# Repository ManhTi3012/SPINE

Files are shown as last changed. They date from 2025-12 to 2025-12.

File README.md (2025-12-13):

# S.P.I.N.E
**Stackable Power Integration & Network Electronics**

<p align="center" style="display: flex; gap: 10px;">
  
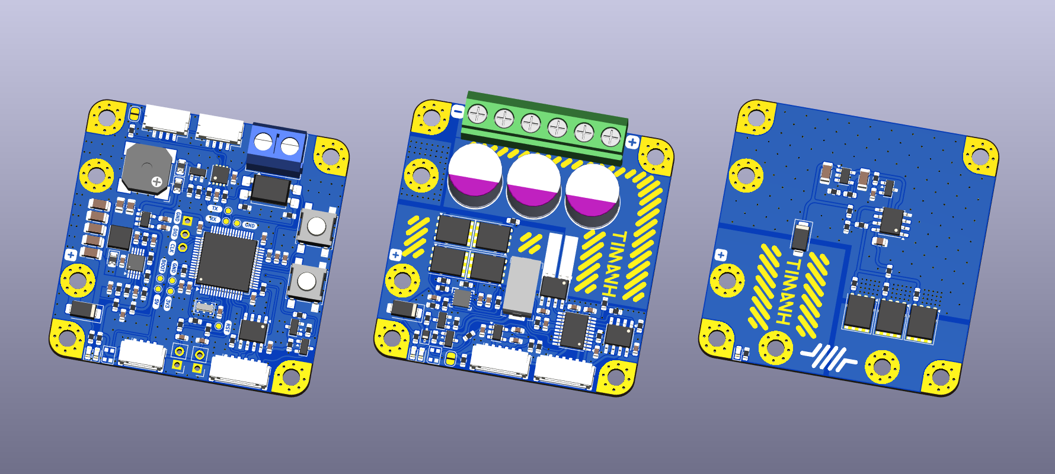
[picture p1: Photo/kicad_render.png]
  
</p>

# Overview
S.P.I.N.E. is a decentralized power distribution architecture that splits control, distribution, and protection into discrete, stackable modules. Offers control and monitor over individual power rails, telemetry via CAN bus, and fault protection like over current, over voltage(due to back EMF), emergency stop.

# System Architecture
The system is composed of three primary module types, functioning analogously to a biological nervous system:

## 1. Cortex (Main Control Unit)
The Cortex is responsible for high-level decision-making and external communication.

- Bus Monitoring: Continuously monitors the main bus voltage.

- Orchestration: Controls the state of all connected Vertebra modules via RS485.

- Telemetry: Send internal system data to the external robot controller via CAN Bus.

## 2. Vertebra (Power Distribution & Switching)
Each Vertebra acts as an intelligent Power Distribution Unit (PDU).

- Distribution: Takes 1 main input and splits it into 3 protected outputs.

- Protection Topology: Utilizes a back-to-back switching topology to enable full bidirectional cutoff.

- Soft Start: Integrated Precharge circuit to prevent inrush current spikes during startup.

- Sensing: Real-time current and voltage sensing on outputs.

- Fault Propagation:

  - Local: Can autonomously cut power upon detecting over-current events.
  
  - Global: A "Critical Fault" in one Vertebra triggers a system-wide shutdown to protect the rest of the hardware.

## 3. Disc (Brake Chopper)
A purely hardware-based protection module.

- Function: Dissipates dangerous back-EMF (voltage spikes) generated by motors during rapid deceleration.

- Mechanism: A fast analog comparator circuit to trigger a dump load when voltage exceeds a set threshold.

- Zero-Latency: No microcontroller or software intervention required; purely reactive hardware protection.

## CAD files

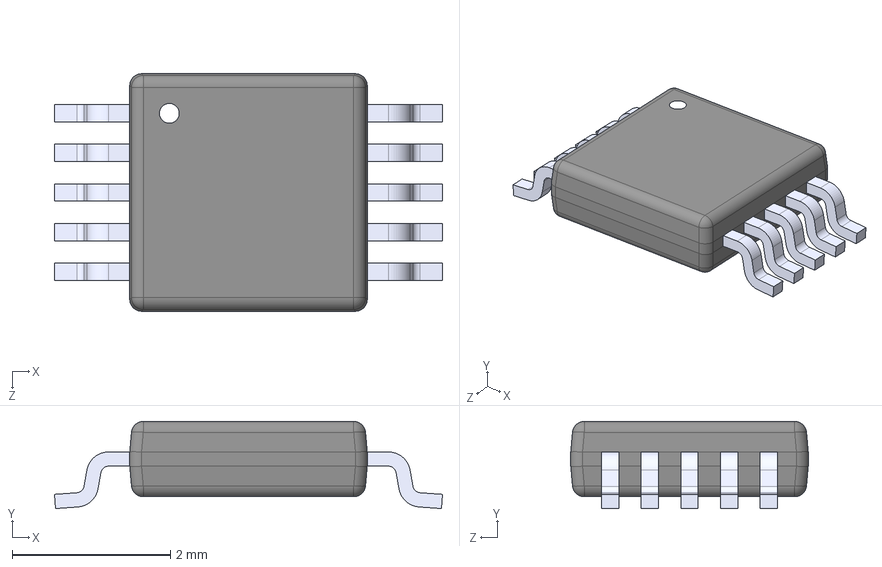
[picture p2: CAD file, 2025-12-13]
Dependencies/HVSSOP-10.STEP
4.90 x 1.10 x 3.00 mm

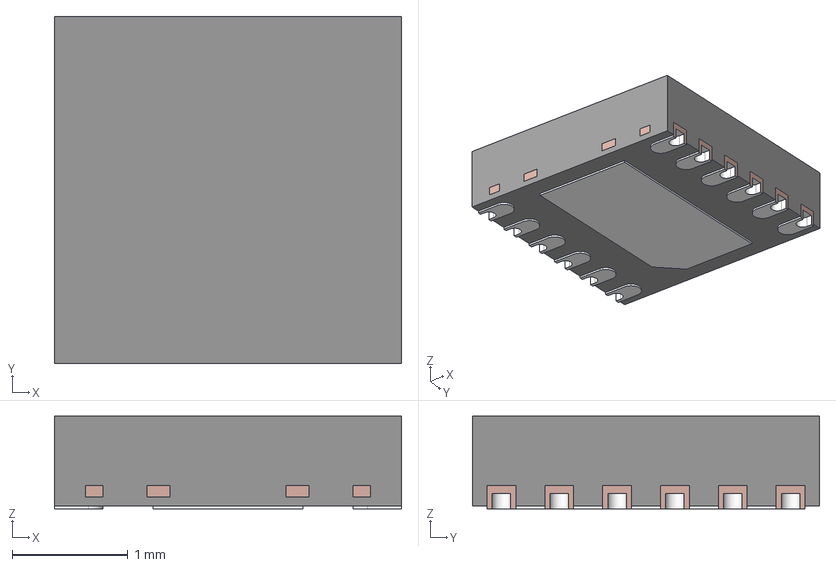
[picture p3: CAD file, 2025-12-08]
Dependencies/ul_LM74800QDRRRQ1/DRR0012E.stp
3.00 x 3.00 x 0.8 mm
BODY-SON_AF0
FRAME-DRR0012D_AF0

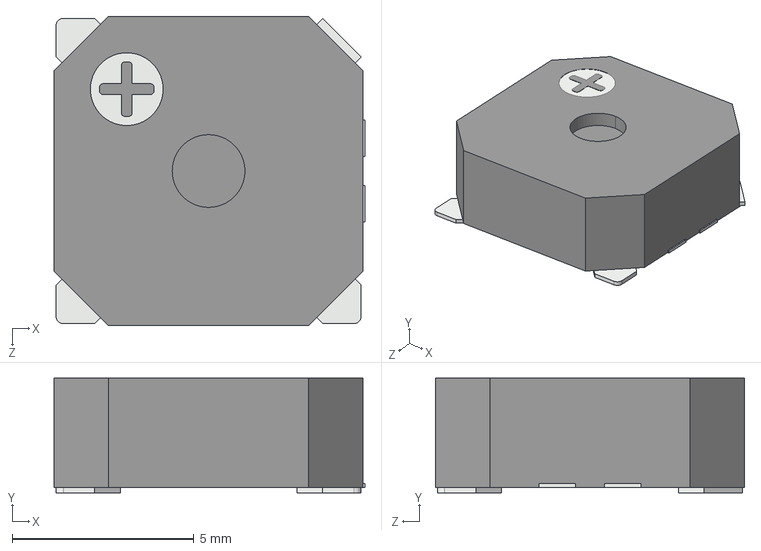
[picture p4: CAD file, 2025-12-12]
Dependencies/GSC8530YA-16R2700.STEP
8.55 x 3.15 x 8.50 mm

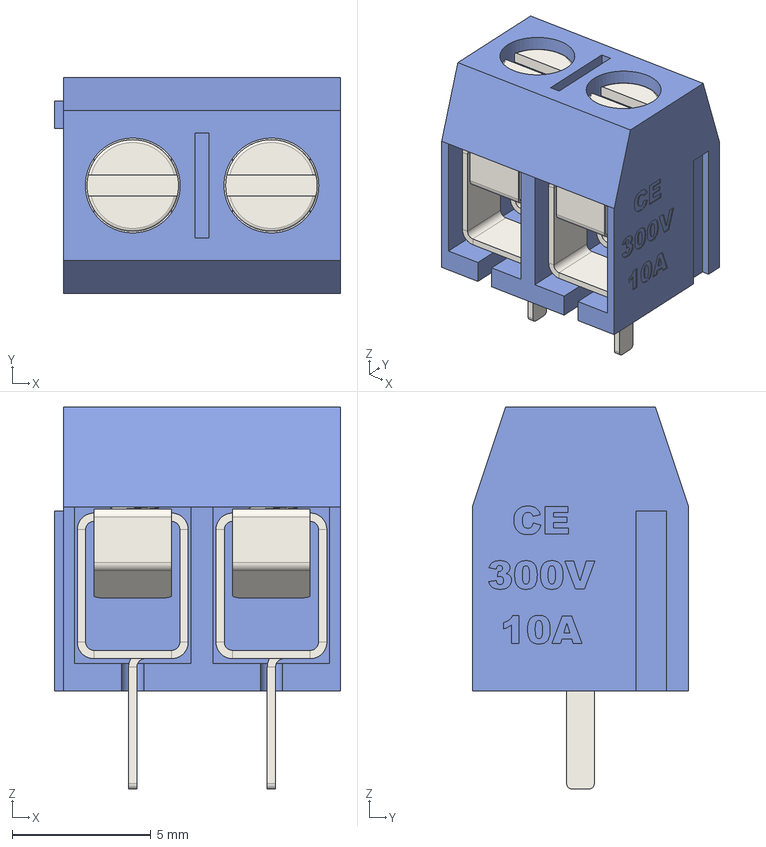
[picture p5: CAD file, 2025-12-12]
Dependencies/dg-301-5_0-2P.step
10.3 x 7.80 x 13.8 mm

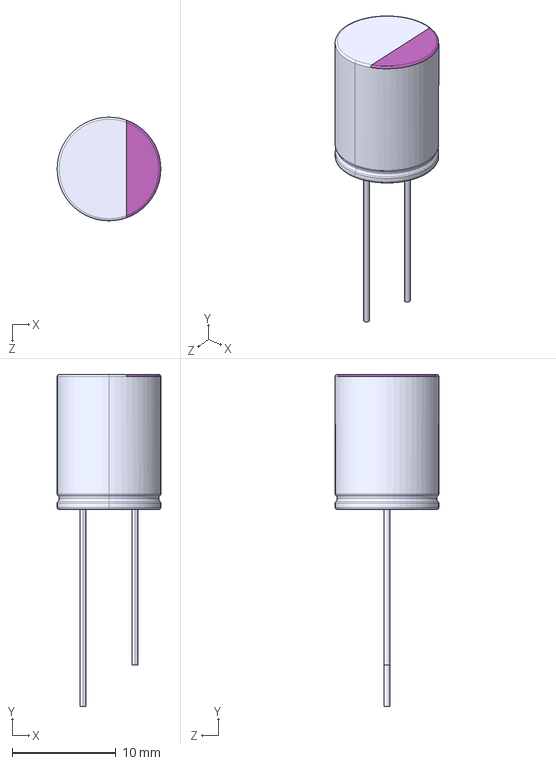
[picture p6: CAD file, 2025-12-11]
Dependencies/35SEPF120M.STEP
10.0 x 32.0 x 10.0 mm

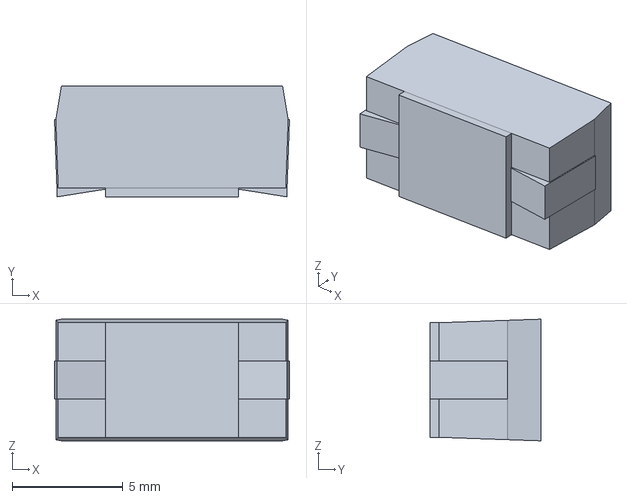
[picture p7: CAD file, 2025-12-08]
Dependencies/c-6-1879021-5-ba-3d.stp
10.6 x 5.00 x 5.50 mm

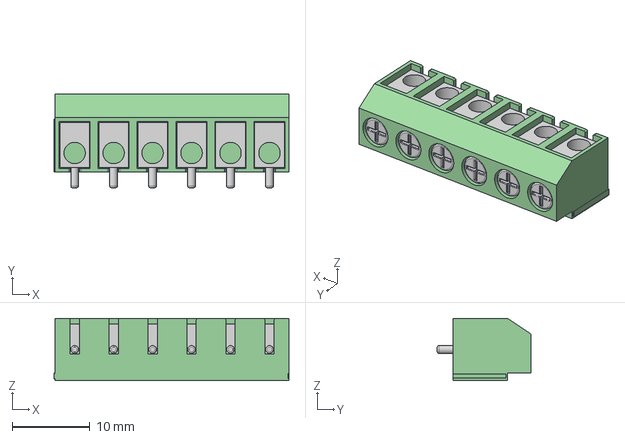
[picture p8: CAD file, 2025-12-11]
Dependencies/Screw Terminal Block 5mm 6-way.step
30.1 x 12.0 x 8.00 mm

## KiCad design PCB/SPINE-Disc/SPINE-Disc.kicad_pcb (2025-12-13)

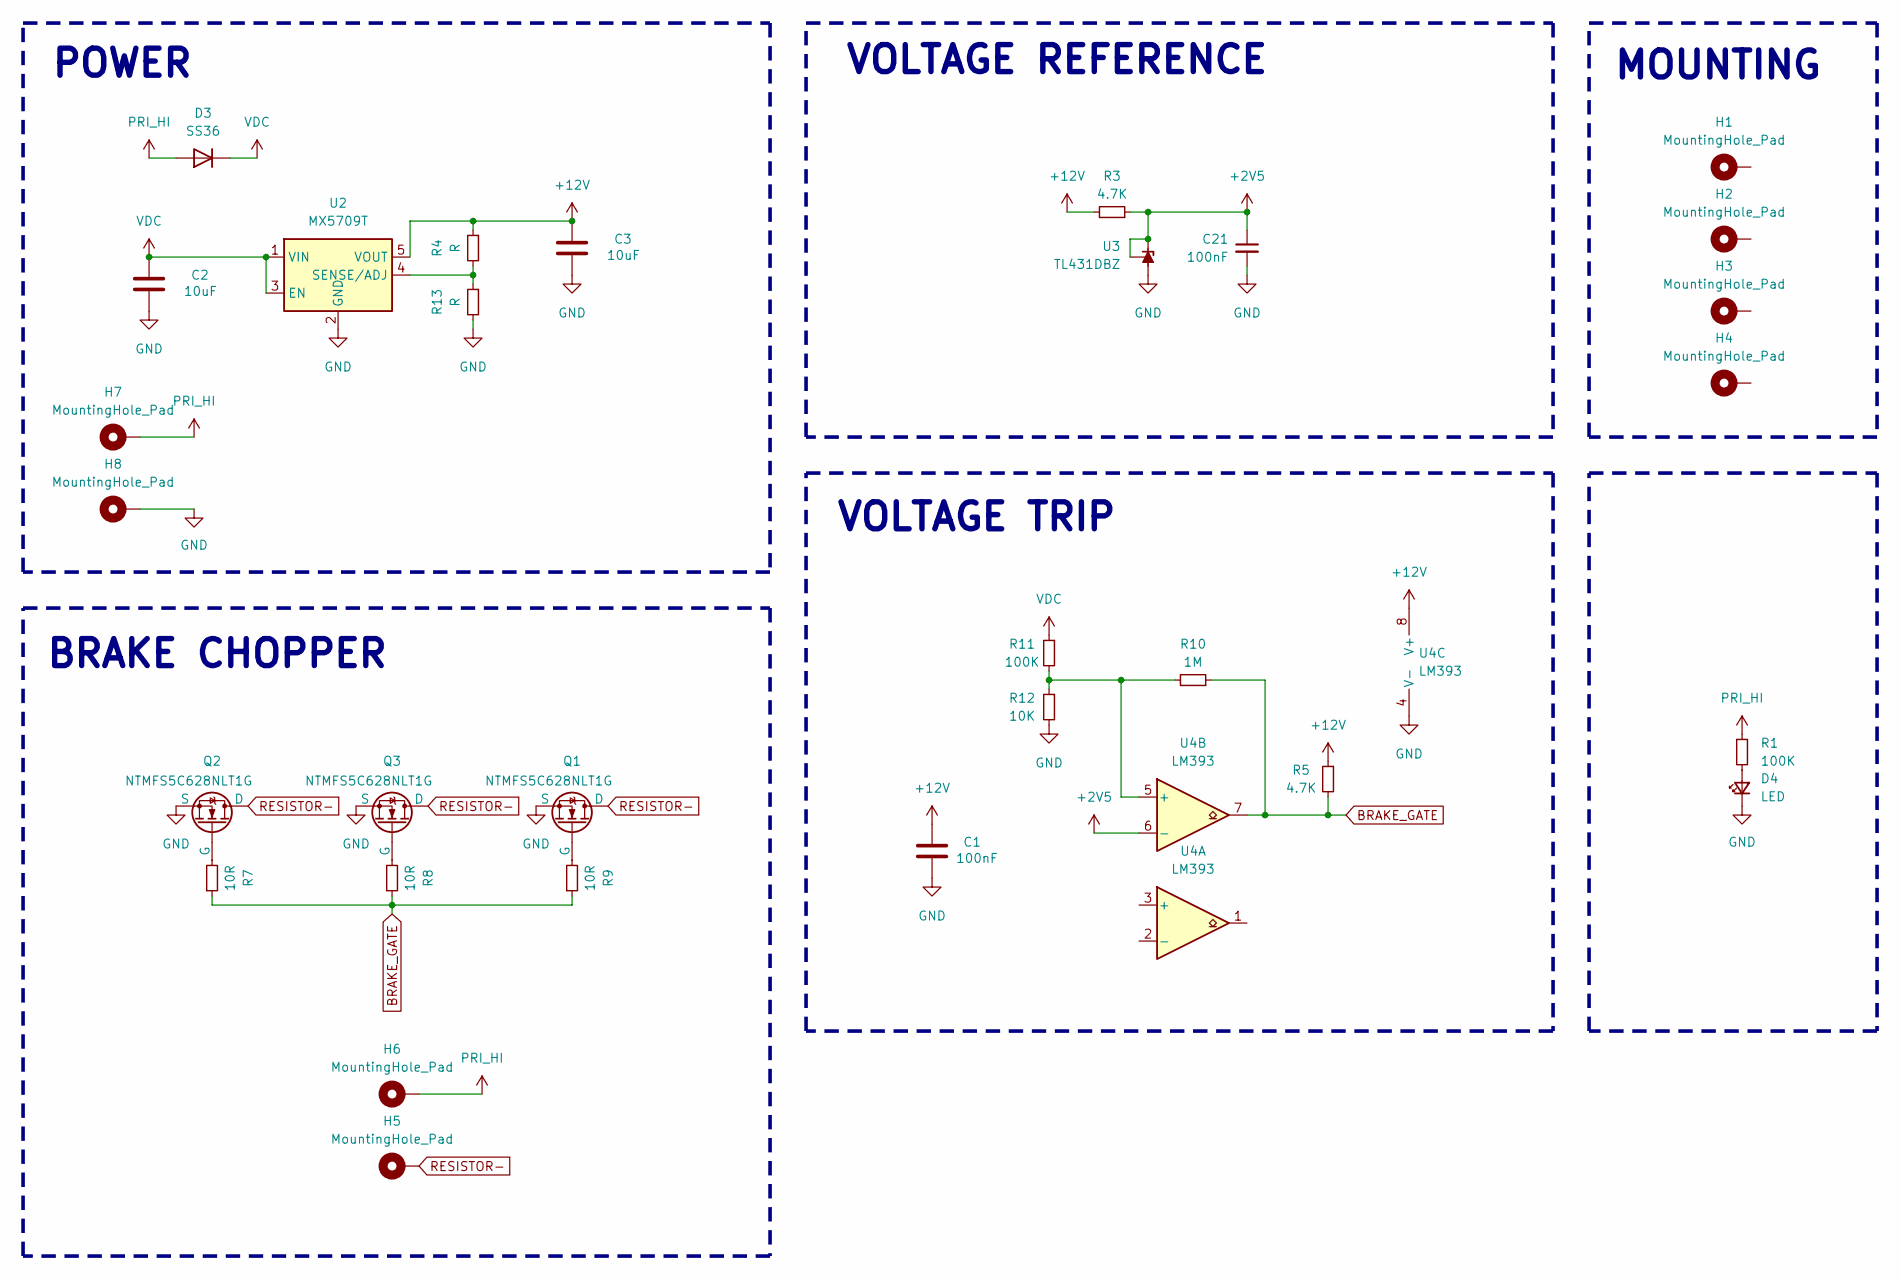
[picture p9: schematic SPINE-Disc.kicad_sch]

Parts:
C1: 100nF; C_0805_2012Metric
C2, C3: 10uF; C_1206_3216Metric
C21: 100nF; C_0603_1608Metric
D3: SS36; D_SMA
D4: LED; LED_0603_1608Metric
H1, H2, H3, H4, H5, H6, H7, H8: MountingHole_Pad; MountingHole_3.2mm_M3_Pad_Via
Q1, Q2, Q3: NTMFS5C628NLT1G; PQFN-8-EP_6x5mm_P1.27mm_Generic
R1, R11: 100K; R_0603_1608Metric
R3, R5: 4.7K; R_0603_1608Metric
R4, R13: R; R_0603_1608Metric
R7, R8, R9: 10R; R_0603_1608Metric
R10: 1M; R_0603_1608Metric
R12: 10K; R_0603_1608Metric
U2: MX5709T; TSOT-23-5
U3: TL431DBZ; SOT-23
U4: LM393; SOIC-8_3.9x4.9mm_P1.27mm

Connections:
+2V5: C21.1, R3.1, U3.1 (K), U3.2 (REF), U4.6 (-)
+12V: C1.2, C3.2, R3.2, R4.1, R5.1, U2.5 (VOUT), U4.8 (V+)
BRAKE_GATE: R5.2, R7.1, R8.1, R9.1, R10.1, U4.7
GND: C1.1, C2.1, C3.1, C21.2, D4.1 (K), H8.1, Q1.1 (S), Q1.2 (S), Q1.3 (S), Q2.1 (S), Q2.2 (S), Q2.3 (S), Q3.1 (S), Q3.2 (S), Q3.3 (S), R12.2, R13.2, U2.2 (GND), U3.3 (A), U4.4 (V-)
unnamed: D4.2 (A), R1.2
unnamed: Q1.4 (G), R9.2
unnamed: Q2.4 (G), R7.2
unnamed: Q3.4 (G), R8.2
unnamed: R4.2, R13.1, U2.4 (SENSE/ADJ)
unnamed: R10.2, R11.2, R12.1, U4.5 (+)
PRI_HI: D3.2 (A), H6.1, H7.1, R1.1
RESISTOR-: H5.1, Q1.5 (D), Q2.5 (D), Q3.5 (D)
VDC: C2.2, D3.1 (K), R11.1, U2.1 (VIN), U2.3 (EN)

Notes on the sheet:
VOLTAGE TRIP
VOLTAGE REFERENCE
POWER
BRAKE CHOPPER
MOUNTING

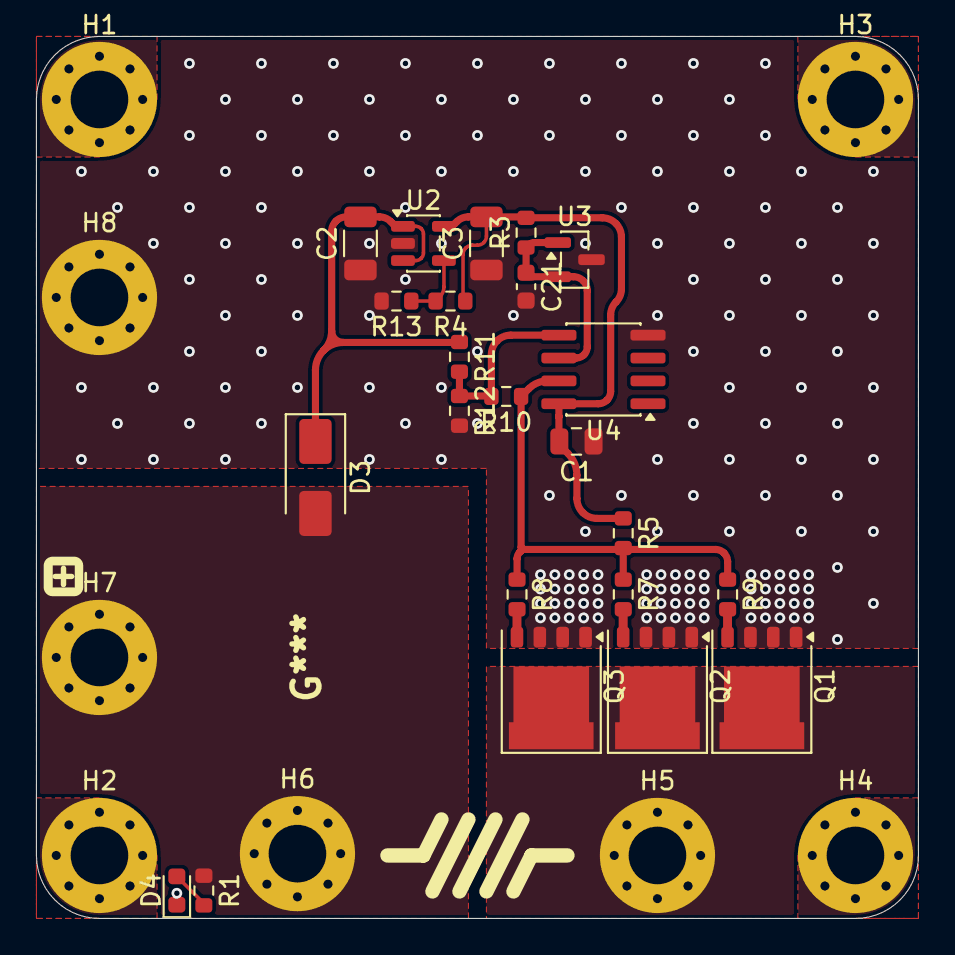
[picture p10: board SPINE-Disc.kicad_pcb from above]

Board: 2 copper layers, 49.0 x 49.0 mm, 31 parts (0 on the bottom side), 13 nets.

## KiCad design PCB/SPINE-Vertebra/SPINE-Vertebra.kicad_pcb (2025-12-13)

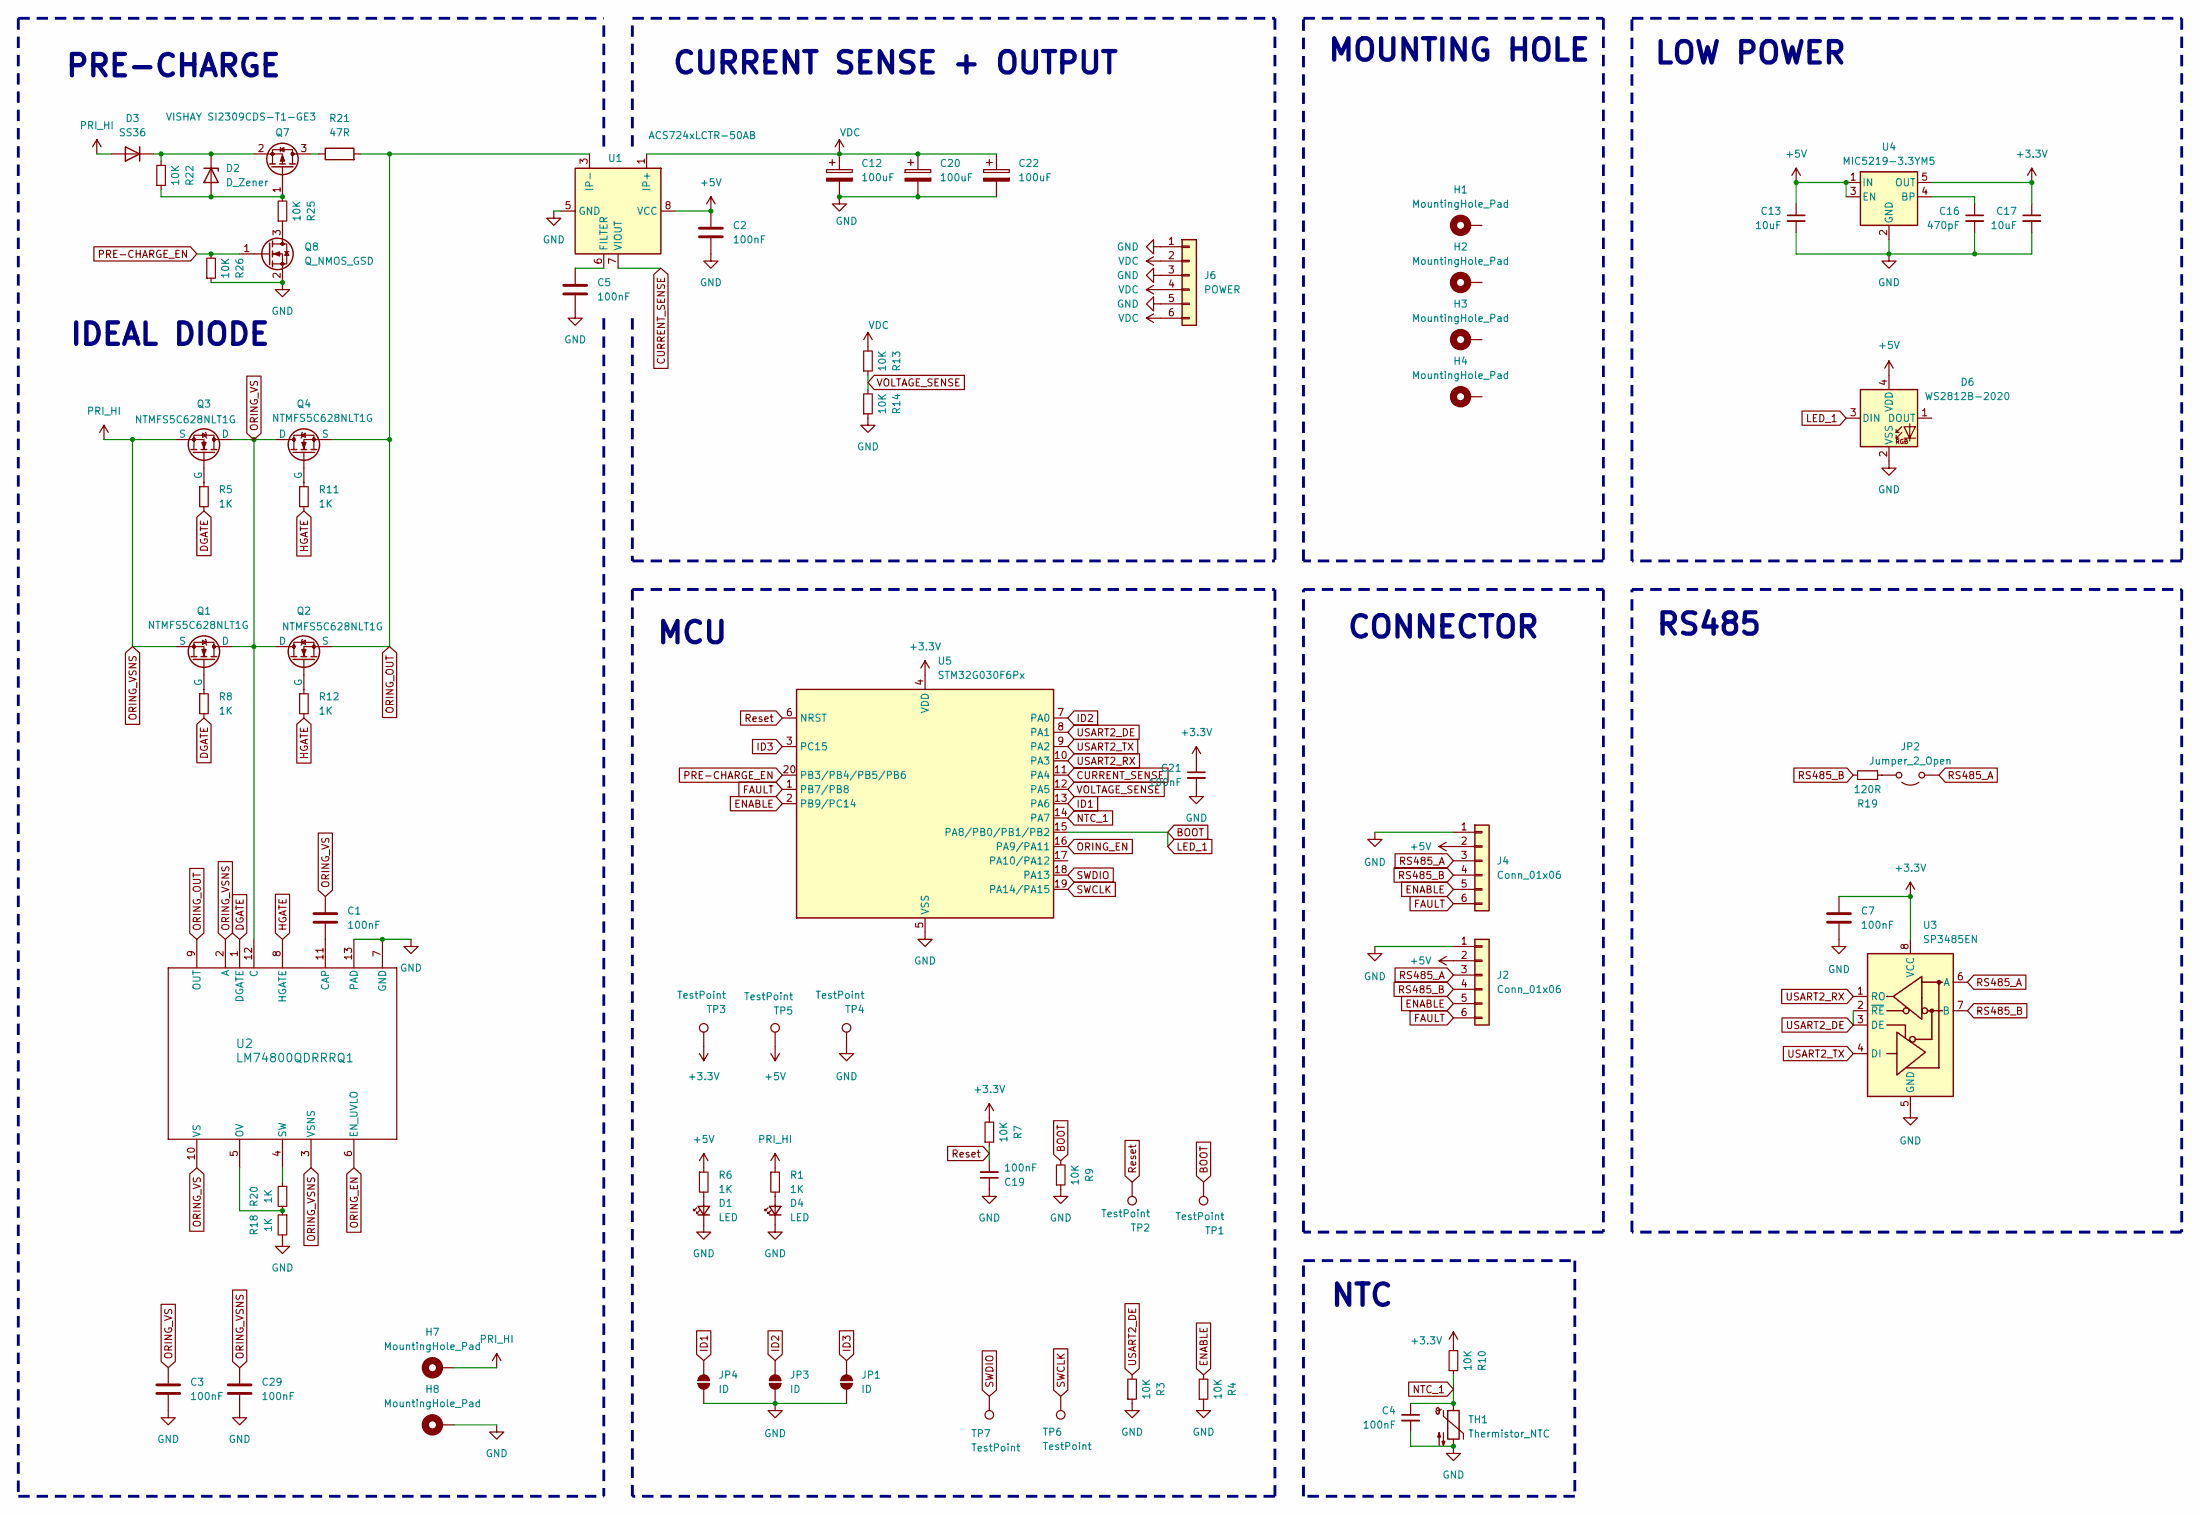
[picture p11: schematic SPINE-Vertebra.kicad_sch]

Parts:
C1, C2, C3, C4, C5, C7, C19, C21, C29: 100nF; C_0603_1608Metric
C12, C20, C22: 100uF; CP_Radial_D10.0mm_P5.00mm
C13, C17: 10uF; C_0603_1608Metric
C16: 470pF; C_0603_1608Metric
D1, D4: LED; LED_0603_1608Metric
D2: D_Zener; D_SOD-323
D3: SS36; D_SMA
D6: WS2812B-2020; LED_WS2812B-2020_PLCC4_2.0x2.0mm
H1, H2, H3, H4, H7, H8: MountingHole_Pad; MountingHole_3.2mm_M3_Pad_Via
J2, J4: Conn_01x06; JST_GH_SM06B-GHS-TB_1x06-1MP_P1.25mm_Horizontal
J6: POWER; TerminalBlock_MetzConnect_Type094_RT03506HBLU_1x06_P5.00mm_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
JP1, JP3, JP4: ID; SolderJumper-2_P1.3mm_Open_TrianglePad1.0x1.5mm
JP2: Jumper_2_Open; SolderJumper-2_P1.3mm_Open_RoundedPad1.0x1.5mm
Q1, Q2, Q3, Q4: NTMFS5C628NLT1G; PQFN-8-EP_6x5mm_P1.27mm_Generic
Q7: VISHAY SI2309CDS-T1-GE3; SOT-23
Q8: Q_NMOS_GSD; SOT-23
R1, R5, R6, R8, R11, R12, R18, R20: 1K; R_0603_1608Metric
R3, R4, R7, R9, R10, R13, R14, R22, R25, R26: 10K; R_0603_1608Metric
R19: 120R; R_0603_1608Metric
R21: 47R; TE-Connect_SM-Series
TH1: Thermistor_NTC; R_0603_1608Metric
TP1, TP2, TP3, TP4, TP5, TP6, TP7: TestPoint; TestPoint_Pad_D1.0mm
U1: ACS724xLCTR-50AB; SOIC-8_3.9x4.9mm_P1.27mm
U2: LM74800QDRRRQ1; DRR0012E
U3: SP3485EN; SOIC-8_3.9x4.9mm_P1.27mm
U4: MIC5219-3.3YM5; SOT-23-5
U5: STM32G030F6Px; TSSOP-20_4.4x6.5mm_P0.65mm

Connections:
+3.3V: C7.2, C17.1, C21.1, R7.2, R10.2, TP3.1, U3.8 (VCC), U4.5 (OUT), U5.4 (VDD)
+5V: C2.2, C13.1, D6.4 (VDD), J2.2, J4.2, R6.1, TP5.1, U1.8 (VCC), U4.1 (IN), U4.3 (EN)
BOOT: D6.3 (DIN), R9.2, TP1.1, U5.15 (PA8/PB0/PB1/PB2)
CURRENT_SENSE: U1.7 (VIOUT), U5.11 (PA4)
DGATE: R5.2, R8.2, U2.1 (DGATE)
ENABLE: J2.5, J4.5, R4.2, U5.2 (PB9/PC14)
FAULT: J2.6, J4.6, U5.1 (PB7/PB8)
GND: C2.1, C3.1, C4.2, C5.1, C7.1, C12.2, C13.2, C16.2, C17.2, C19.1, C20.2, C21.2, C22.2, C29.1, D1.1 (K), D4.1 (K), D6.2 (VSS), H8.1, J2.1, J4.1, J6.1, J6.3, J6.5, JP1.2 (B), JP3.2 (B), JP4.2 (B), Q8.2 (S), R3.1, R4.1, R9.1, R14.1, R18.2, R26.1, TH1.2, TP4.1, U1.5 (GND), U2.7 (GND), U2.13 (PAD), U3.5 (GND), U4.2 (GND), U5.5 (VSS)
HGATE: R11.2, R12.2, U2.8 (HGATE)
ID1: JP4.1 (A), U5.13 (PA6)
ID2: JP3.1 (A), U5.7 (PA0)
ID3: JP1.1 (A), U5.3 (PC15)
NTC_1: C4.1, R10.1, TH1.1, U5.14 (PA7)
unnamed: D1.2 (A), R6.2
unnamed: D2.2 (A), Q7.1 (G), R22.1, R25.2
unnamed: D2.1 (K), D3.1 (K), Q7.2 (S), R22.2
unnamed: D4.2 (A), R1.2
unnamed: JP2.2 (B), R19.1
unnamed: Q1.4 (G), R8.1
unnamed: Q2.4 (G), R12.1
unnamed: Q3.4 (G), R5.1
unnamed: Q4.4 (G), R11.1
unnamed: Q7.3 (D), R21.1
unnamed: Q8.3 (D), R25.1
unnamed: C5.2, U1.6 (FILTER)
unnamed: C1.1, U2.11 (CAP)
unnamed: R18.1, R20.2, U2.5 (OV)
unnamed: R20.1, U2.4 (SW)
unnamed: C16.1, U4.4 (BP)
ORING_EN: U2.6 (EN_UVLO), U5.16 (PA9/PA11)
ORING_OUT: Q2.1 (S), Q2.2 (S), Q2.3 (S), Q4.1 (S), Q4.2 (S), Q4.3 (S), R21.2, U1.3 (IP-), U1.4 (IP-), U2.9 (OUT)
ORING_VS: C1.2, C3.2, Q1.5 (D), Q2.5 (D), Q3.5 (D), Q4.5 (D), U2.10 (VS), U2.12 (C)
ORING_VSNS: C29.2, D3.2 (A), H7.1, Q1.1 (S), Q1.2 (S), Q1.3 (S), Q3.1 (S), Q3.2 (S), Q3.3 (S), R1.1, U2.2 (A), U2.3 (VSNS)
PRE-CHARGE_EN: Q8.1 (G), R26.2, U5.20 (PB3/PB4/PB5/PB6)
RS485_A: J2.3, J4.3, JP2.1 (A), U3.6 (A)
RS485_B: J2.4, J4.4, R19.2, U3.7 (B)
Reset: C19.2, R7.1, TP2.1, U5.6 (NRST)
SWCLK: TP6.1, U5.19 (PA14/PA15)
SWDIO: TP7.1, U5.18 (PA13)
USART2_DE: R3.2, U3.2 (~RE), U3.3 (DE), U5.8 (PA1)
USART2_RX: U3.1 (RO), U5.10 (PA3)
USART2_TX: U3.4 (DI), U5.9 (PA2)
VDC: C12.1, C20.1, C22.1, J6.2, J6.4, J6.6, R13.2, U1.1 (IP+), U1.2 (IP+)
VOLTAGE_SENSE: R13.1, R14.2, U5.12 (PA5)

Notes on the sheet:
MOUNTING HOLE
CONNECTOR
IDEAL DIODE
MCU
RS485
LOW POWER
PRE-CHARGE
CURRENT SENSE + OUTPUT
NTC

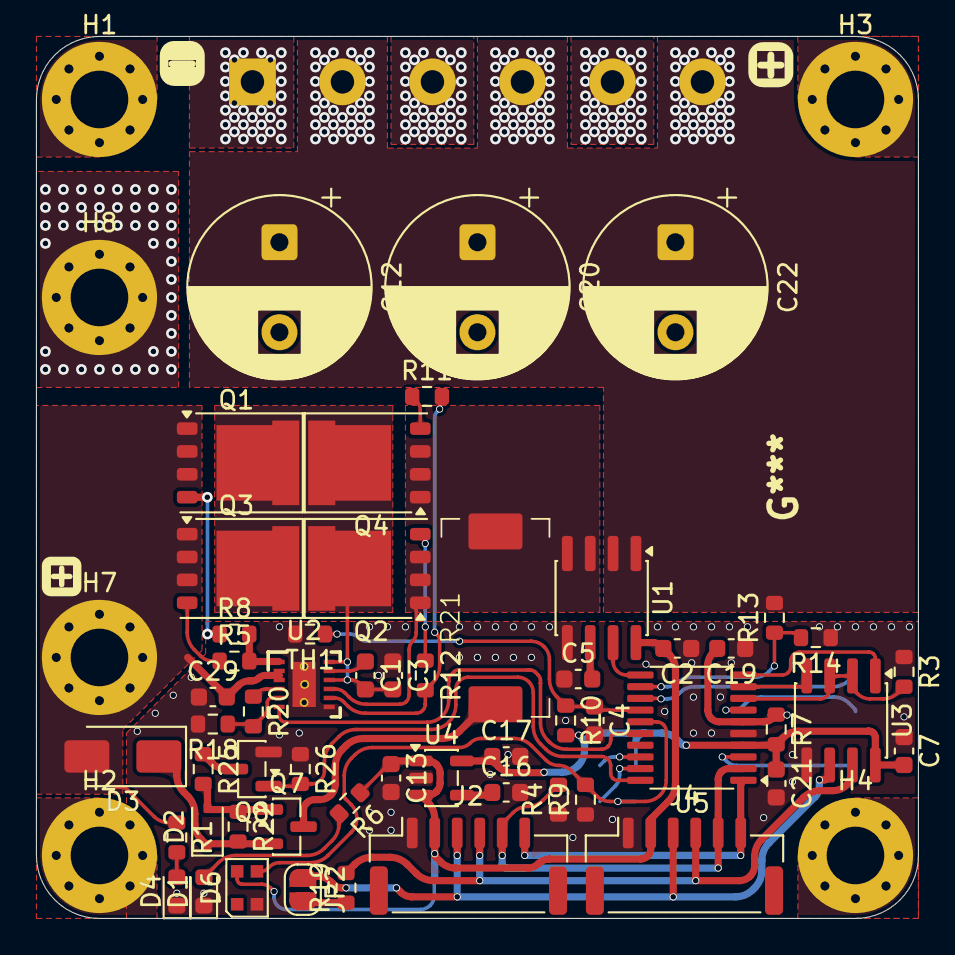
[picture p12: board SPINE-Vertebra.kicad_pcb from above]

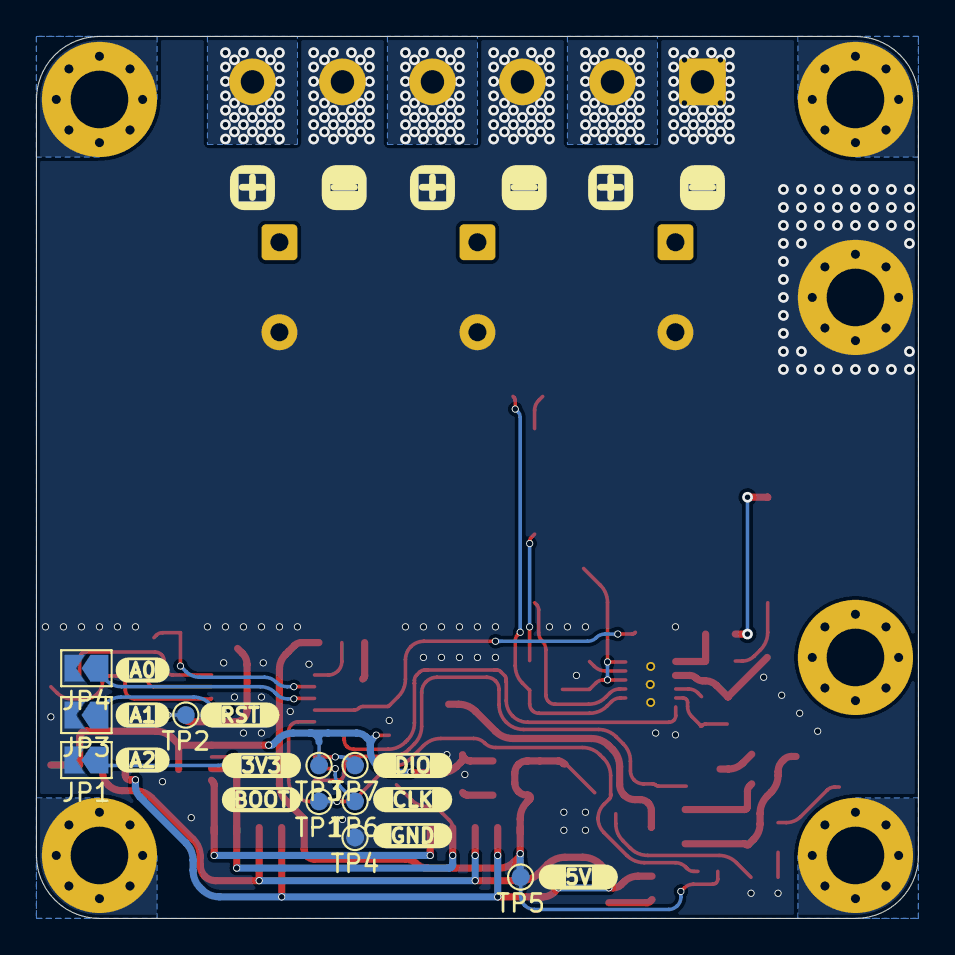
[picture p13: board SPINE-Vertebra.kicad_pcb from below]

Board: 2 copper layers, 49.0 x 49.0 mm, 72 parts (10 on the bottom side), 44 nets.

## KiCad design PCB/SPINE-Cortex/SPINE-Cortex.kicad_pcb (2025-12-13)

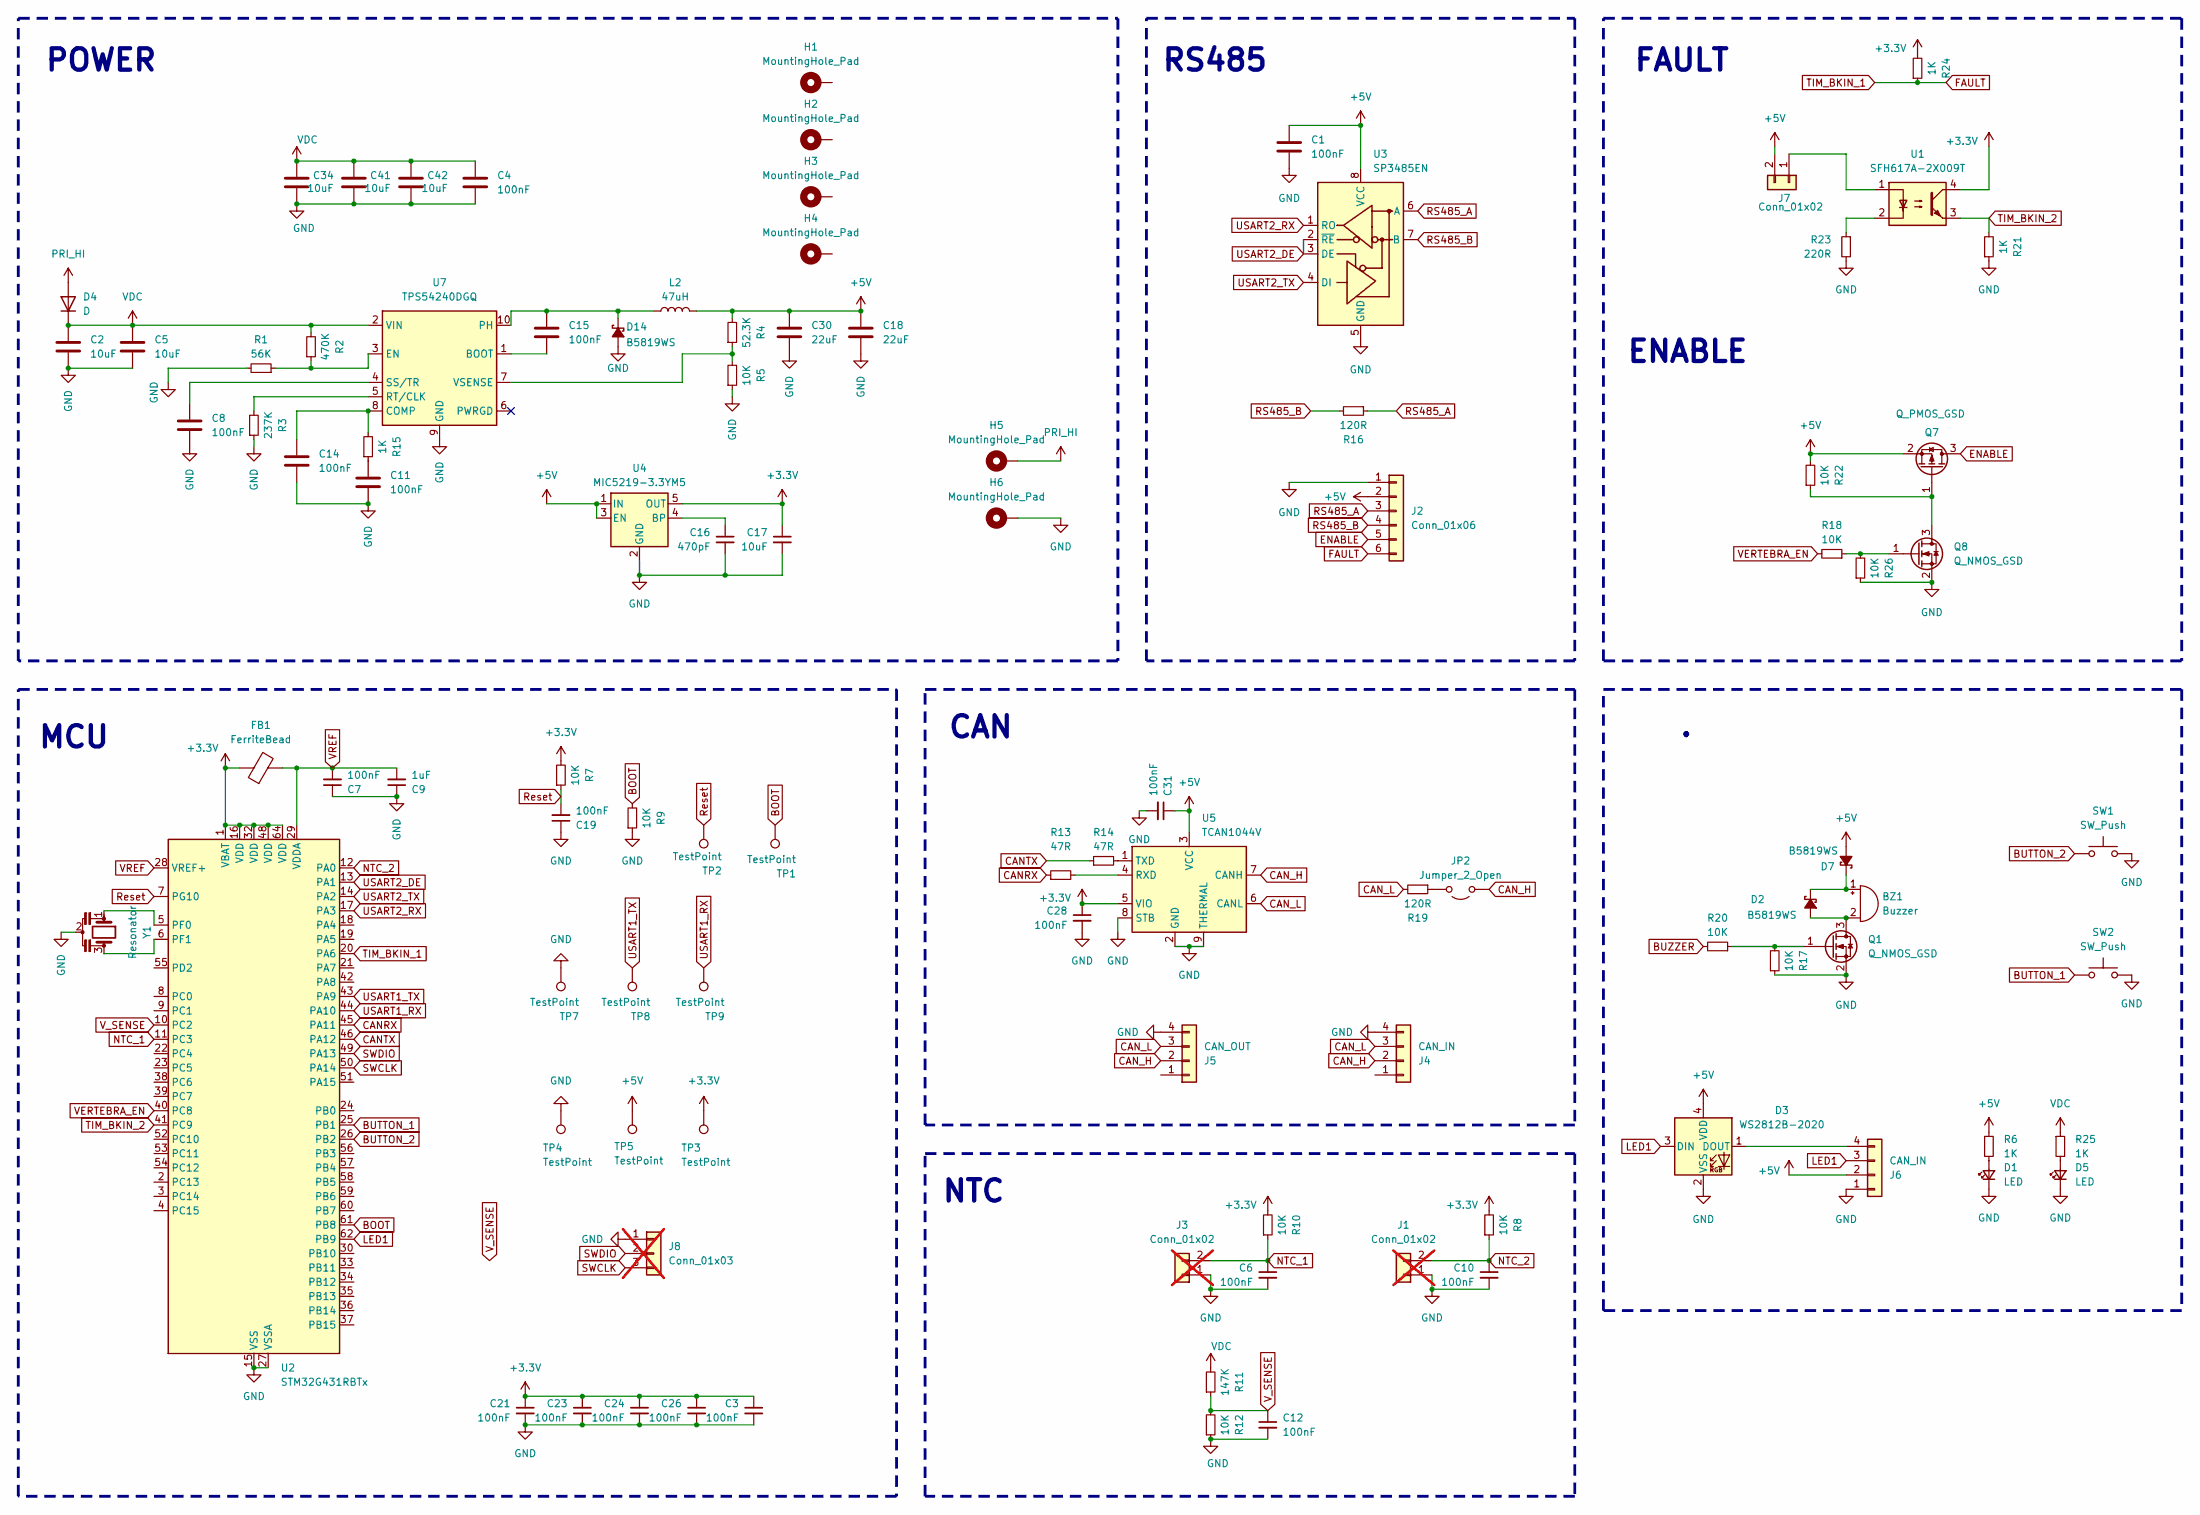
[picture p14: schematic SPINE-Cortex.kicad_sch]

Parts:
BZ1: Buzzer; MagneticBuzzer_CUI_CMT-8504-100-SMT
C1, C3, C4, C6, C7, C8, C10, C11, C12, C14, C15, C19, C21, C23, C24, C26, C28, C31: 100nF; C_0603_1608Metric
C2, C5, C34, C41, C42: 10uF; C_1206_3216Metric
C9: 1uF; C_0603_1608Metric
C16: 470pF; C_0603_1608Metric
C17: 10uF; C_0603_1608Metric
C18, C30: 22uF; C_0805_2012Metric
D1, D5: LED; LED_0603_1608Metric
D2, D7, D14: B5819WS; D_0805_2012Metric
D3: WS2812B-2020; LED_WS2812B-2020_PLCC4_2.0x2.0mm
D4: D; D_SMA
FB1: FerriteBead; L_0603_1608Metric
H1, H2, H3, H4, H5, H6: MountingHole_Pad; MountingHole_3.2mm_M3_Pad_Via
J1, J3: Conn_01x02; PinHeader_1x02_P2.54mm_Vertical; not fitted
J2: Conn_01x06; JST_GH_SM06B-GHS-TB_1x06-1MP_P1.25mm_Horizontal
J4, J6: CAN_IN; JST_GH_SM04B-GHS-TB_1x04-1MP_P1.25mm_Horizontal
J5: CAN_OUT; JST_GH_SM04B-GHS-TB_1x04-1MP_P1.25mm_Horizontal
J7: Conn_01x02; TerminalBlock_MetzConnect_Type094_RT03502HBLU_1x02_P5.00mm_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
J8: Conn_01x03; PinHeader_1x03_P2.54mm_Vertical; not fitted
JP2: Jumper_2_Open; SolderJumper-2_P1.3mm_Open_RoundedPad1.0x1.5mm
L2: 47uH; L_APV_ANR4020
Q1, Q8: Q_NMOS_GSD; SOT-23
Q7: Q_PMOS_GSD; SOT-23
R1: 56K; R_0603_1608Metric
R2: 470K; R_0603_1608Metric
R3: 237K; R_0603_1608Metric
R4: 52.3K; R_0603_1608Metric
R5, R7, R8, R9, R10, R12, R17, R18, R20, R22, R26: 10K; R_0603_1608Metric
R6, R15, R21, R24, R25: 1K; R_0603_1608Metric
R11: 147K; R_0603_1608Metric
R13, R14: 47R; R_0603_1608Metric
R16, R19: 120R; R_0603_1608Metric
R23: 220R; R_0603_1608Metric
SW1, SW2: SW_Push; SW_SPST_B3S-1000
TP1, TP2, TP3, TP4, TP5, TP7, TP8, TP9: TestPoint; TestPoint_Pad_D1.0mm
U1: SFH617A-2X009T; SMDIP-4_W9.53mm_Clearance8mm
U2: STM32G431RBTx; LQFP-64_10x10mm_P0.5mm
U3: SP3485EN; SOIC-8_3.9x4.9mm_P1.27mm
U4: MIC5219-3.3YM5; SOT-23-5
U5: TCAN1044V; Texas_S-PVSON-N8
U7: TPS54240DGQ; HVSSOP-10-1EP_3x3mm_P0.5mm_EP1.57x1.88mm_ThermalVias
Y1: Resonator; Resonator_SMD_Murata_CSTxExxV-3Pin_3.0x1.1mm

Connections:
+3.3V: C3.1, C17.1, C21.1, C23.1, C24.1, C26.1, C28.1, FB1.1, R7.2, R8.2, R10.2, R24.2, TP3.1, U1.4, U2.1 (VBAT), U2.16 (VDD), U2.32 (VDD), U2.48 (VDD), U2.64 (VDD), U4.5 (OUT), U5.5 (VIO)
+5V: C1.2, C18.2, C30.2, C31.1, D3.4 (VDD), D7.2 (A), J2.2, J6.2, J7.2, L2.2, Q7.2 (S), R4.2, R6.1, R22.2, TP5.1, U3.8 (VCC), U4.1 (IN), U4.3 (EN), U5.3 (VCC)
BOOT: R9.2, TP1.1, U2.61 (PB8)
BUTTON_1: SW2.1, U2.25 (PB1)
BUTTON_2: SW1.1, U2.26 (PB2)
BUZZER: R20.2
CANRX: R13.1, U2.45 (PA11)
CANTX: R14.1, U2.46 (PA12)
CAN_H: J4.2, J5.2, JP2.1 (A), U5.7 (CANH)
CAN_L: J4.3, J5.3, R19.2, U5.6 (CANL)
ENABLE: J2.5, Q7.3 (D)
FAULT: J2.6, R24.1, U2.20 (PA6)
GND: C1.1, C2.1, C3.2, C4.1, C5.1, C6.2, C7.1, C8.1, C9.1, C10.2, C11.1, C12.2, C14.1, C16.2, C17.2, C18.1, C19.1, C21.2, C23.2, C24.2, C26.2, C28.2, C30.1, C31.2, C34.1, C41.1, C42.1, D1.1 (K), D3.2 (VSS), D5.1 (K), D14.2 (A), H6.1, J1.1, J2.1, J3.1, J4.4, J5.4, J6.1, J8.1, Q1.2 (S), Q8.2 (S), R1.2, R3.1, R5.1, R9.1, R12.1, R17.1, R21.1, R23.2, R26.1, SW1.2, SW2.2, TP4.1, TP7.1, U2.15 (VSS), U2.27 (VSSA), U2.31 (VSS), U2.47 (VSS), U2.63 (VSS), U3.5 (GND), U4.2 (GND), U5.2 (GND), U5.8 (STB), U5.9 (THERMAL), U7.9 (GND), U7.11 (GND), Y1.2
LED1: D3.3 (DIN), J6.3, U2.62 (PB9)
NTC_1: C6.1, J3.2, R10.1, U2.11 (PC3)
NTC_2: C10.1, J1.2, R8.1, U2.12 (PA0)
unnamed: BZ1.1 (+), D2.1 (K), D7.1 (K)
unnamed: BZ1.2 (-), D2.2 (A), Q1.3 (D)
unnamed: C11.2, R15.1
unnamed: D1.2 (A), R6.2
unnamed: D3.1 (DOUT), J6.4
unnamed: D5.2 (A), R25.2
unnamed: C15.2, D14.1 (K), L2.1, U7.10 (PH)
unnamed: J7.1, U1.1
unnamed: JP2.2 (B), R19.1
unnamed: Q1.1 (G), R17.2, R20.1
unnamed: Q7.1 (G), Q8.3 (D), R22.1
unnamed: Q8.1 (G), R18.1, R26.2
unnamed: R23.1, U1.2
unnamed: U2.5 (PF0), Y1.1
unnamed: U2.6 (PF1), Y1.3
unnamed: C16.1, U4.4 (BP)
unnamed: R13.2, U5.4 (RXD)
unnamed: R14.2, U5.1 (TXD)
unnamed: C15.1, U7.1 (BOOT)
unnamed: C14.2, R15.2, U7.8 (COMP)
unnamed: R1.1, R2.1, U7.3 (EN)
unnamed: R3.2, U7.5 (RT/CLK)
unnamed: C8.2, U7.4 (SS/TR)
unnamed: R4.1, R5.2, U7.7 (VSENSE)
PRI_HI: D4.2 (A), H5.1
RS485_A: J2.3, R16.1, U3.6 (A)
RS485_B: J2.4, R16.2, U3.7 (B)
Reset: C19.2, R7.1, TP2.1, U2.7 (PG10)
SWCLK: J8.3, U2.50 (PA14)
SWDIO: J8.2, U2.49 (PA13)
TIM_BKIN_2: R21.2, U1.3, U2.41 (PC9)
USART1_RX: TP9.1, U2.44 (PA10)
USART1_TX: TP8.1, U2.43 (PA9)
USART2_DE: U2.13 (PA1), U3.2 (~RE), U3.3 (DE)
USART2_RX: U2.17 (PA3), U3.1 (RO)
USART2_TX: U2.14 (PA2), U3.4 (DI)
VDC: C2.2, C4.2, C5.2, C34.2, C41.2, C42.2, D4.1 (K), R2.2, R11.2, R25.1, U7.2 (VIN)
VERTEBRA_EN: R18.2, U2.40 (PC8)
VREF: C7.2, C9.2, FB1.2, U2.28 (VREF+), U2.29 (VDDA)
V_SENSE: C12.1, R11.1, R12.2, U2.10 (PC2)

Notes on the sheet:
CAN
FAULT
MCU
RS485
POWER
NTC
ENABLE

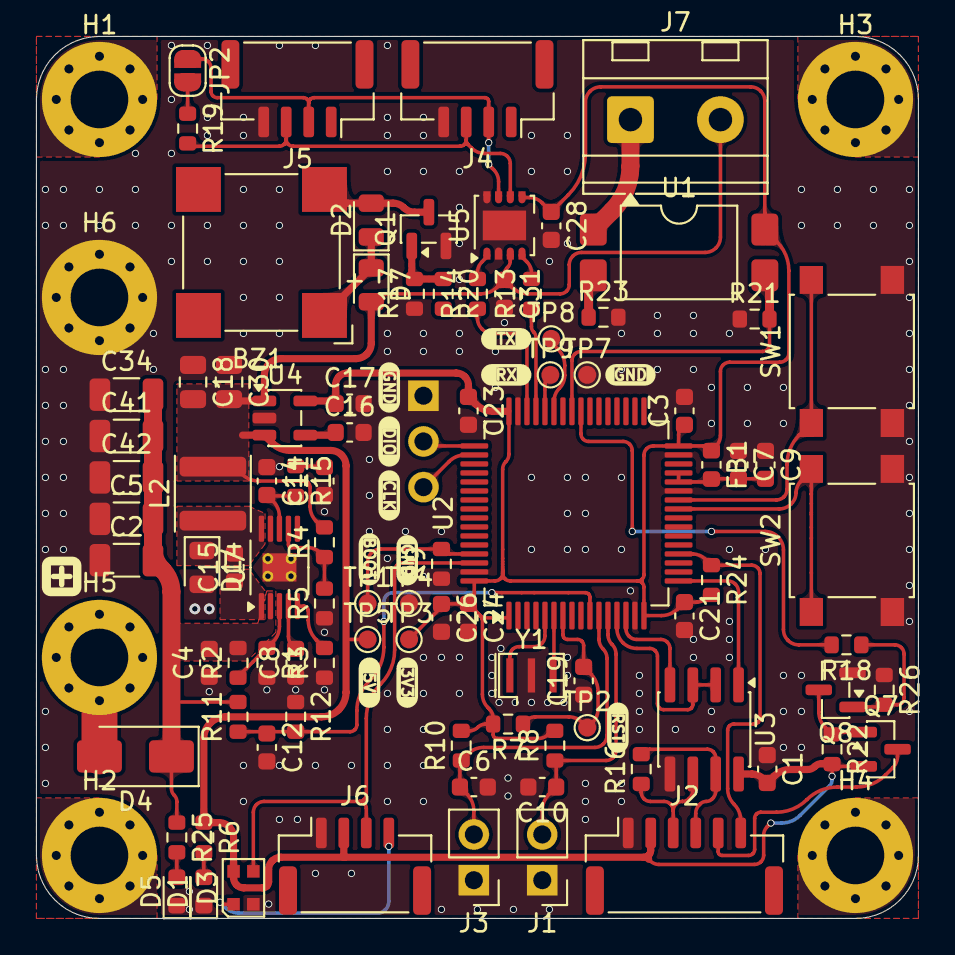
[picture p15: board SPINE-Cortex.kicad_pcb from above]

Board: 2 copper layers, 49.0 x 49.0 mm, 99 parts (1 on the bottom side), 55 nets.

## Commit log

2025-12-08 vertebra update
    [DRR0012E.stp, SPINE-Cortex.kicad_pcb, SPINE-Cortex.kicad_sch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]
2025-12-09 Finish Vertebra
    [SPINE-Cortex.kicad_pcb, SPINE-Cortex.kicad_sch, SPINE-Disc.kicad_pcb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]
2025-12-11 Vertebra fix
    [35SEPF120M.STEP, SPINE-Cortex.kicad_pcb, SPINE-Cortex.kicad_sch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]
